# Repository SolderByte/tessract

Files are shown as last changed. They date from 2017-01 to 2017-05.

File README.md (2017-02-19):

# tessract

### BOM:
* x3 47 Ohm resistors
* x1 330 Ohm resistor
* x2 10k Ohm resistor
* x1 100k Ohm resistor
* x2 10 uF Capacitor
* x2 .1 uF Capacitor
* x1 4.7 uF Capacitor
* x1 Push button switch
* x1 LED
* x1 Li-Ion Battery
* x1 Micro USB
* x1 ATMEL ATtiny85
* x1 Microchip MCP73832
* x1 Microchip MCP1755 (MIC5504 alternative)
* x1 Osram LRTB GFTG

### Current consumption:

| Part | Current |
|---|---|
| ATMEL ATtiny85 | 3mA = 3.3V @ 8MHz, 5mA = 5V @ 8MHz |
| HM-10  | 50mA = 3.3V (active 8.5mA, sleep 50-200uA)  |
| OSRAM LRTB GFTG  | Red = 5-40mA, Green = 5-50mA, Blue = 5-50mA  |

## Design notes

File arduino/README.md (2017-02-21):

# tessract

Arduino instructions

1. Download and install Arduino
2. Add ATtiny support
  * Arduino > Preferences > "Additional Boards Manager URLs "boards manager
  * Add the following json URL [json](https://raw.githubusercontent.com/damellis/attiny/ide-1.6.x-boards-manager/package_damellis_attiny_index.json)
  * Arduino > Tools > Board > Boards Manager
  * Download and Install the attiny
3. Select ATtiny Board
  * Arduino > Tools > Board > ATtiny25/45/85
4. Select ATtiny85 processor
  * Arduino > Tools > Processor > ATtiny85
5. Select Internal 8MHz
  * Arduino > Tools > Clock > Internal 8MHz

Programmer instructions

1. Add a 10uF capacitor to the Arduino board between RESET and GND
2. Select the Programmer
  * Arduino > Tools > Programmer > Arduino as ISP
3. Burn bootloader to make it run at 8MHz

| Arduino Pin | ATtiny85 Pin |
|---|---|
| 5V | VCC |
| GND | GND |
| Pin 10 | RESET |
| Pin 11 | Pin 0 |
| Pin 12 | Pin 1 |
| Pin 13 | Pin 2 |

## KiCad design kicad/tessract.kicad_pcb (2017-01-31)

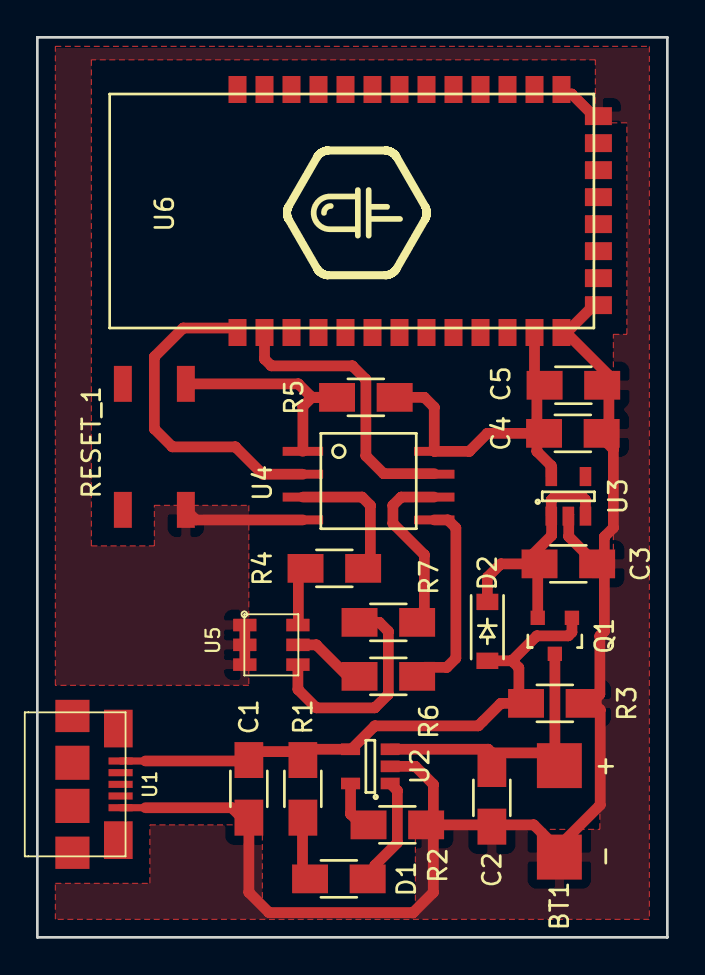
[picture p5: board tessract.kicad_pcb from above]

Board: 2 copper layers, 35.0 x 50.0 mm, 25 parts (1 on the bottom side), 17 nets.

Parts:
BT1: Battery; SMD_BATT
C1, C3: 10uF; SMD_1206
C2: 4.7uF; SMD_1206
C4, C5: .1uF; SMD_1206
D1: LED; SMD_1206
D2: B130LAW; SOD_123
Q1: DMP1045U; SOT_23
R1: 330; SMD_1206
R2, R5: 10k; SMD_1206
R3: 100k; SMD_1206
R4, R6, R7: 47; SMD_1206
RESET_1: SW_PUSH; TL3305_SWITCH
U1: MICRO_B_USB
U2: MCP73832T; SOT_23_5
U3: MCP1755; SOT_23_5
U4: ATMEL_ATTINY85_20SU; SOIC8_EIAJ_208MIL
U5: OSRAM_LRTB_GFTG; OSRAM_RGB_LED
U6: HM-10
solderbyte_logo: G***; solderbyte_logo_25mm
solderbyte_logo#2: G***; SOLDERBYTE_LOGO_20MM

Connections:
Earth: BT1.2, C1.2, C2.2, C3.2, C4.2, C5.2, R2.2, R3.1, RESET_1.1, U1.5, U2.2, U3.2, U4.4, U5.1, U5.2, U5.3, U6.13, U6.14, U6.21, U6.22
unnamed: BT1.1, C2.1, Q1.3, U2.3
unnamed: C1.1, D2.2, Q1.1, R1.1, R3.2, U1.1, U2.4
unnamed: C3.1, D2.1, Q1.2, U3.1, U3.3
unnamed: C4.1, C5.1, R5.1, U3.5, U4.8, U6.12
unnamed: D1.1, U2.1
unnamed: D1.2, R1.2
unnamed: R2.1, U2.5
unnamed: R4.1, U5.6
unnamed: R4.2, U4.3
unnamed: R5.2, RESET_1.2, U4.1
unnamed: R6.1, U5.5
unnamed: R6.2, U4.5
unnamed: R7.1, U5.4
unnamed: R7.2, U4.6
unnamed: U4.2, U6.1
unnamed: U4.7, U6.2

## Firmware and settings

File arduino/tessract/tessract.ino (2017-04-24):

#include <SoftwareSerial.h>

SoftwareSerial bleSerial(3, 2);
// SoftwareSerial(rxPin, txPin)
// RX is digital pin 3 (connect to TX of other device)
// TX is digital pin 2 (connect to RX of other device)
//
// ATtiny85     HM-10
// ------------------
// Pin 3    <-  TX
// Pin 2    ->  RX

/*              Protocol
---------------------------------------------
| 00000000 | 00000000 | 00000000 | 00000000 |
---------------------------------------------
    |           |           |           |
    |           |           |           |
    v           v           v           v
  Command      Red        Green       Blue
    |
    |
    |--> 000000XX Action {00: Off, 01: On, 10: Blink, 11: Pulse}
    |
    |--> 0000XX00 Blink/Pulse amount {00: 1, 01: 2, 10: 3, 11: 5}
    |
    |--> 00XX0000 Blink/Pulse duration {00: Fastest, 01: Fast, 10: Normal, 11: Slow}
    |
    |--> XX000000 Blink/Pulse Repeat {00: 0, 01: 5 secs, 10: 15 secs, 11: 30 secs}
*/

// Data
unsigned char COMMAND;
unsigned char RED;
unsigned char GREEN;
unsigned char BLUE;

// Defaults
int ACTION = 0;
int AMOUNT = 0;
int DURATION = 0;
int REPEAT = 0;
int MAP_ACTION[] = {0, 1, 2, 3};
int MAP_AMOUNT[] = {1, 2, 3, 5};
int MAP_DURATION[] = {50, 100, 250, 500};
int MAP_REPEAT[] = {0, 5000, 15000, 30000};

// LED
int REDPIN = 1;
int GREPIN = 0;
int BLUPIN = 4;

// Time
int TIMESTAMP = 0;

void setup() {
  // Set pins for LEDs as outputs
  pinMode(REDPIN, OUTPUT);
  pinMode(GREPIN, OUTPUT);
  pinMode(BLUPIN, OUTPUT);

  // HM-10 defaults to 9600 baud rate
  bleSerial.begin(9600);

  // Configure the HM-10 module
  delay(250);
  bleSerial.print("AT+ROLE0"); // Slave mode (0: Peripheral, 1: Central, default: 0)
  delay(250);
  bleSerial.print("AT+MODE2"); // (0: Tranmission, 1: PIO+0, 2: Remote Control+0, default: 0)
  delay(250);
  bleSerial.print("AT+IMME1"); // (0: Work immediately, 1: wait for AT+ commands, wait for AT+START to resume work, default: 0) Don't enter transmission mode until told. ("AT+IMME0" is wait until "AT+START" to work. "AT+WORK1" is connect right away.)
  delay(250);
  bleSerial.print("AT+BAUD0"); // (0: 9600, 1: 19200, 2: 38400, 3: 57600, 4: 115200)
  delay(250);
  bleSerial.print("AT+NAMETessract"); // Set name
  delay(250);
  bleSerial.print("AT+PASS123456"); // Set password
  delay(250);
  bleSerial.print("AT+START"); // Work immediately when AT+IMME1 is set.
  delay(250);

  TIMESTAMP = millis();
}

void loop() {
  // Check for data
  if (bleSerial.available()) {
    // Read in data
    while (bleSerial.available()) {
      COMMAND = bleSerial.read();
      delay(1);
      RED = bleSerial.read();
      delay(1);
      GREEN = bleSerial.read();
      delay(1);
      BLUE = bleSerial.read();
      delay(1);
    }

    // Parse command
    parseCommands();

    // Run command
    runCommands();
  }
}

/* Parses the COMMAND variable according to the protocol
 * @returns {void}
 */
void parseCommands() {
  // Reset to defaults
  ACTION = 0;
  AMOUNT = 0;
  DURATION = 0;
  REPEAT = 0;

  // Shift out values
  REPEAT = COMMAND & 3;
  COMMAND >>= 2;
  DURATION = COMMAND & 3;
  COMMAND >>= 2;
  AMOUNT = COMMAND & 3;
  COMMAND >>= 2;
  ACTION = COMMAND & 3;
}

/* Executes the commands
 * @returns {void}
 */
void runCommands() {
  // Turn off
  if (ACTION == MAP_ACTION[0]) {
    toggleLed(0, 0, 0);
  }

  // Turn on
  if (ACTION == MAP_ACTION[1]) {
    toggleLed(RED, GREEN, BLUE);
  }

  // Blink
  if (ACTION == MAP_ACTION[2]) {
    blinkLed(MAP_AMOUNT[AMOUNT], MAP_DURATION[DURATION], RED, GREEN, BLUE);
  }

  // Pulse
  if (ACTION == MAP_ACTION[3]) {
    pulseLed(MAP_AMOUNT[AMOUNT], MAP_DURATION[DURATION], RED, GREEN, BLUE);
  }

  // Repeat
  if (REPEAT > MAP_REPEAT[0]) {
    int now = millis();
    int diff = now - TIMESTAMP;

    if (diff > MAP_REPEAT[REPEAT]) {
      TIMESTAMP = millis();
      runCommands();
    }
  }
}

/* Blinks the LED
 * @param {Integer} amount - The amount of times to blink
 * @param {Integer} duratiion - The duration (ms) in between blinks
 * @param {Integer} red - The value of red
 * @param {Integer} green - The value of green
 * @param {Integer} blue - The value of blue
 * @returns {void}
 */
void blinkLed(int amount, int duration, unsigned char red, unsigned char green, unsigned char blue) {
  // Iterate over amount of blinks
  for (int i = 0; i < amount; i++) {
    analogWrite(REDPIN, red);
    analogWrite(GREPIN, green);
    analogWrite(BLUPIN, blue);
    delay(duration);
    analogWrite(REDPIN, 0);
    analogWrite(GREPIN, 0);
    analogWrite(BLUPIN, 0);
    delay(duration);
  }
}

/* Pulses the LED
 * @param {Integer} amount - The amount of times to blink
 * @param {Integer} duratiion - The duration (ms) in between blinks
 * @param {Integer} red - The value of red
 * @param {Integer} green - The value of green
 * @param {Integer} blue - The value of blue
 * @returns {void}
 */
void pulseLed(int amount, int duration, unsigned char red, unsigned char green, unsigned char blue) {
  // Convert duration
  int _delay = 1;
  if (duration == MAP_DURATION[3]) {
    _delay = 8;
  } else if (duration == MAP_DURATION[2]) {
    _delay = 5;
  } else if (duration == MAP_DURATION[1]) {
    _delay = 3;
  } else if (duration == MAP_DURATION[0]) {
    _delay = 1;
  }

  // Iterate over amount of pulses
  for (int i = 0; i < amount; i++) {
    // Pulse up
    for (int j = 0; j < 255; j++) {
      if (j <= red) {
        analogWrite(REDPIN, j);
      }
      if (j <= green) {
        analogWrite(GREPIN, j);
      }
      if (j <= blue) {
        analogWrite(BLUPIN, j);
      }
      // Magic delay
      if (j <= 55) {
        delay(_delay);
      }
      delay(_delay);
    }

    // Pulse down
    for (int k = 255; k >= 0; k--) {
      if (k <= red) {
        analogWrite(REDPIN, k);
      }
      if (k <= green) {
        analogWrite(GREPIN, k);
      }
      if (k <= blue) {
        analogWrite(BLUPIN, k);
      }
      delay(_delay);
    }

    // Wait
    delay(100);
  }
}

/* Toggles LEDs
 * @param {Integer} red - The value of red
 * @param {Integer} green - The value of green
 * @param {Integer} blue - The value of blue
 * @returns {void}
 */
void toggleLed(unsigned char red, unsigned char green, unsigned char blue) {
  analogWrite(REDPIN, red);
  analogWrite(GREPIN, green);
  analogWrite(BLUPIN, blue);
}

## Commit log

2016-10-17 kicad project
    [tessract.kicad_pcb, tessract.sch]
2016-10-17 kicad libs
2016-10-19 solderbyte library
2016-11-01 setting up schematic
    [tessract.sch]
2016-11-10 added mcp1755 and mosfet
    [tessract.sch]
2016-12-05 schematic draft
    [tessract.sch]
2016-12-20 add footprints
    [tessract.sch]
2016-12-30 add pcb layout
    [tessract.kicad_pcb]
2017-01-01 copper plane
    [tessract.kicad_pcb]
2017-01-13 organize silkscreen
    [tessract.kicad_pcb]
2017-01-17 wider track and silkscreen logo
    [tessract.kicad_pcb]
2017-01-31 removed library
    [tessract.kicad_pcb, tessract.sch]
2017-02-21 arduino and android first pass
    [app_bar_main.xml]
2017-03-07 android connect dialog
    [app_bar_main.xml]
2017-04-24 arduino test and protocol
2017-05-02 android dialog color class and device activity
